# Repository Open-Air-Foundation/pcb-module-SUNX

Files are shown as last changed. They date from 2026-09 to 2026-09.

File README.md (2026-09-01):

# AirGradient SUNX CO₂ Sensor Module — Hardware

> KiCad hardware design files for the AirGradient SUNX CO₂ sensor module — a plug-in adapter board that carries a SenseAir Sunrise/Sunlight ("SUNX") NDIR CO₂ sensor in AirGradient air quality monitors, including the [Open Air Max](https://www.airgradient.com/professional/products/open-air-max/).

## Overview

A 2-layer adapter for the SenseAir Sunrise/Sunlight family: two sockets matching the sensor's 5-pin and 4-pin headers, an HT7333 3.3 V LDO with bulk decoupling for the sensor supply, and a solder jumper (JP1) for sensor power selection. Power and UART are routed to an 8-pin host connector.

This is the SUNX-only variant of AirGradient's CO₂ sensor adapter family — v2.0 of the original combined design with S8 support removed; the [S8-only board](https://github.com/Open-Air-Foundation/pcb-module-s8) and the [combined S8 + SUNX board](https://github.com/Open-Air-Foundation/pcb-module-s8-sunx) live in their own repositories.

## Design structure

A single KiCad project in `sunx/`: one schematic sheet and a 2-layer board.

## Repository structure

```
sunx/                        # KiCad project (schematic + board), production/
```

## Key components

| Function | Part | Ref |
|---|---|---|
| Sensor sockets (5-pin + 4-pin) | Pin sockets, 2.54 mm | J1, J2 |
| 3.3 V LDO (sensor supply) | HT7333-3 (SOT-89) | U1 |
| Bulk decoupling | 2× 10 µF, 2× 22 µF | C1–C4 |
| Sensor power select (3-way solder jumper) | — | JP1 |
| Host connector (8-pin) | Molex | con1 |

## Toolchain

- **KiCad 9** (file format 2025-01). All symbols, footprints, and 3D models come from the KiCad standard libraries — the project opens without any extra library setup.

## Fabrication

`sunx/production/` holds the released set: Gerber zip (`sunx-v2.0.zip`; the Gerber filenames inside keep the design's original `CO2-sensor-pcb` naming), BOM, and pick-and-place positions.

## Versioning & releases

Hardware revisions are tagged on this repository. Per-version release notes and the matching production file set are published on the [GitHub Releases](../../releases) page.

> The `v2.1` branch carries work in progress (AP2112K-3.3 LDO, 0 Ω power-select links replacing the solder jumper, revised silkscreen and placement). It is untested and unreleased — do not order from it.

## License

This is open-source hardware. The design files in this repository are licensed under the
[Creative Commons Attribution-ShareAlike 4.0 International (CC BY-SA 4.0)](https://creativecommons.org/licenses/by-sa/4.0/) license — see [LICENSE](LICENSE).

You are free to use, modify, and manufacture these designs, including commercially, provided you credit AirGradient and share derivative designs under the same license.

## Maintainers

AirGradient hardware team.

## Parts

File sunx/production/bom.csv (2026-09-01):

Id | Designator | Footprint | Quantity | Designation | Supplier and ref
1 | JP6,JP5,JP4,JP3,JP2,JP1 | SolderJumper-2_P1.3mm_Bridged_RoundedPad1.0x1.5mm | 6 | SolderJumper_2_Open
2 | J2,J1 | PinHeader_1x05_P2.54mm_Vertical | 2 | Conn_01x05_Socket
3 | U1 | SOT-89-3 | 1 | HT7333-3-SOT89
4 | JP9 | SolderJumper-3_P1.3mm_Bridged12_RoundedPad1.0x1.5mm_NumberLabels | 1 | SolderJumper_3_Open
5 | con1 | Molex_PicoBlade_53261-0871_1x08-1MP_P1.25mm_Horizontal | 1 | Conn_01x08_MountingPin
6 | C1,C2 | C_0603_1608Metric | 2 | 10uf / 25V
7 | JP11,JP12,JP13,JP10 | SolderJumper-2_P1.3mm_Open_RoundedPad1.0x1.5mm | 4 | SolderJumper_2_Open

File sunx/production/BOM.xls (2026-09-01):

Comment | Designator | Footprint | JLCPCB Part #（optional）
Molex_PicoBlade_53261-0871_1x08-1MP_P1.25mm_Horizontal | con1 | Molex_PicoBlade_53261-0871_1x08-1MP_P1.25mm_Horizontal | C2845385
HT7333-3-SOT89 | U1 | SOT89 | C84207
10uF/25V | C1,C2 | C_0603 | C96446

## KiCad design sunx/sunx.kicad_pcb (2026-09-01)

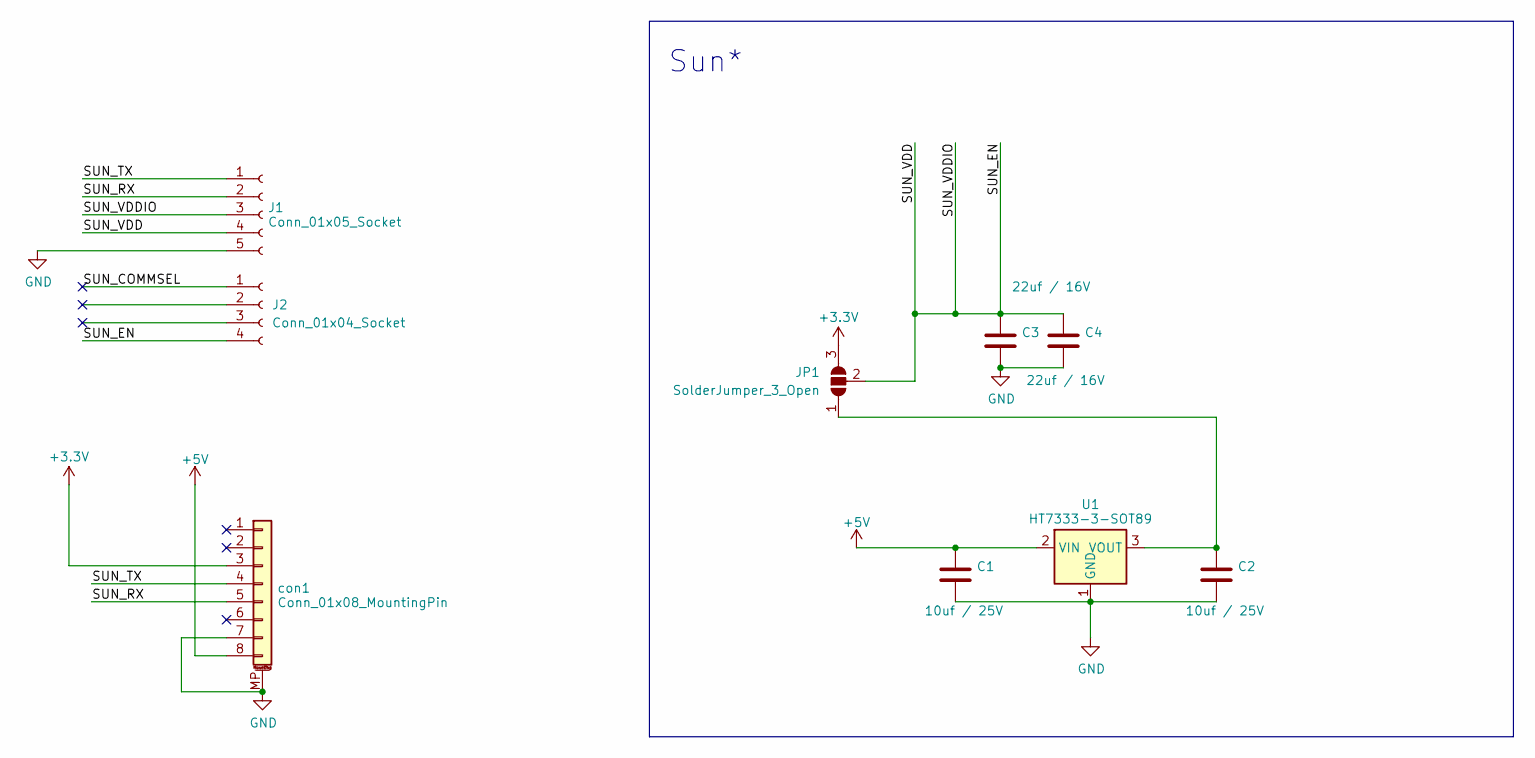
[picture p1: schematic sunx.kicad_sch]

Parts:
C1, C2: 10uf / 25V; C_0603_1608Metric
C3, C4: 22uf / 16V; C_0603_1608Metric
J1: Conn_01x05_Socket; PinHeader_1x05_P2.54mm_Vertical
J2: Conn_01x04_Socket; PinHeader_1x04_P2.54mm_Vertical
JP1: SolderJumper_3_Open; SolderJumper-3_P1.3mm_Bridged12_RoundedPad1.0x1.5mm_NumberL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
U1: HT7333-3-SOT89; SOT-89-3
con1: Conn_01x08_MountingPin; Molex_PicoBlade_53261-0871_1x08-1MP_P1.25mm_Horizontal

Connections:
+3.3V: JP1.3 (B), con1.3
+5V: C1.1, U1.2 (VIN), con1.8
/SUN_COMMSEL: J2.1
/SUN_EN: C3.1, C4.1, J1.3, J1.4, J2.4, JP1.2 (C)
/SUN_RX: J1.2, con1.5
/SUN_TX: J1.1, con1.4
GND: C1.2, C2.2, C3.2, C4.2, J1.5, U1.1 (GND), con1.7, con1.MP (MountPin)
unnamed: C2.1, JP1.1 (A), U1.3 (VOUT)

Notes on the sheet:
Sun*

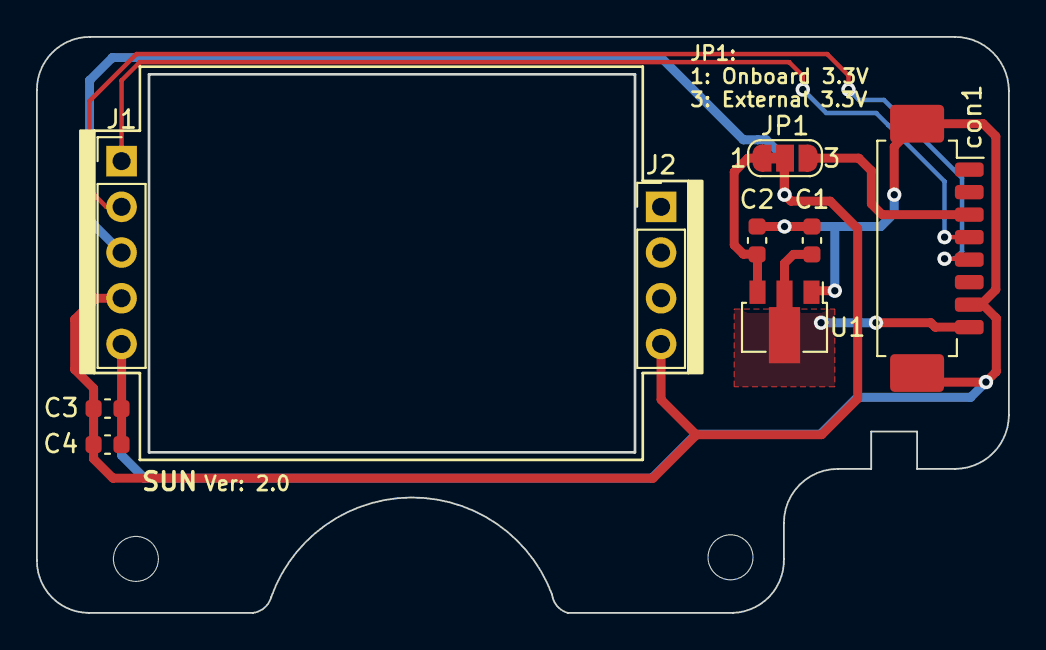
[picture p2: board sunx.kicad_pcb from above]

Board: 2 copper layers, 54.0 x 32.0 mm, 9 parts (0 on the bottom side), 7 nets.
